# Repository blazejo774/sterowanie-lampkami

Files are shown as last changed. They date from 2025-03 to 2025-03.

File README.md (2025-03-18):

# 🔴🟢🔵 Sterowanie Lampkami Choinkowymi

Projekt ma sterować serią diod LED, poprzez zmienianie ustawień diód na jedno z wielu ustawień, z których użytkownik może wybrać przystosowane dla niego oświetlenie. Projekt zaweria różne rodzaje oświetlenia, miedzy innymi:

- [ ] Oscylacja światełek czerwonych, zielonych lub niebieskich.
- [ ] Włączenie bądź wyłączenie poszczególnych kolorów.
- [ ] Inne niestandardowe ustawienia oświetlenia.

Można rozszerzyć ilość używanych diod, poprzez dodanie więcej gałęzi po 3 diody:
 - Zamiast 1 gałęzi z 3 diodami, tworzysz np. 7 równoległych gałęzi po 3 diody w szeregu.
 - Każda gałąź dostaje swój rezystor, np. 7 rezystorów po 120Ω dla zielonych LED-ów.
 - MOSFET steruje wszystkimi 7 gałęziami naraz.
 
👉 Zalety: Nie zmienia się napięcie, MOSFET łatwo steruje większą ilością diod.

## 📝 Dokumentacja

ℹ Kod → [**Dokumentacja**](https://github.com/blazejo774/sterowanie-lampkami/blob/d19fd1ce32649a07414ba25e057f50cffe792c03/%5BCODE%5D/main.c)

ℹ Wykaz elementów → [**Dokumentacja**](https://github.com/blazejo774/sterowanie-lampkami/blob/d19fd1ce32649a07414ba25e057f50cffe792c03/%5BELECTRONICS%5D/readme.md)

## ⭐ Software

💾 Kod → [**main.c**](https://github.com/blazejo774/sterowanie-lampkami/blob/d19fd1ce32649a07414ba25e057f50cffe792c03/%5BCODE%5D/main.c)

## 💡 Hardware

💾 Schemat Elektryczny → [**Schemat Elektryczny**](https://github.com/blazejo774/sterowanie-lampkami/blob/d19fd1ce32649a07414ba25e057f50cffe792c03/%5BELECTRONICS%5D/scheme.pdf)

💾 Schemat Płytki PCB TOP → [**Płytka-TOP**](https://github.com/blazejo774/sterowanie-lampkami/blob/d19fd1ce32649a07414ba25e057f50cffe792c03/%5BBOARD%5D/Board_TOP.pdf)

💾 Schemat Płytki PCB BOTTOM → [**Płytka-BOTTOM**](https://github.com/blazejo774/sterowanie-lampkami/blob/d19fd1ce32649a07414ba25e057f50cffe792c03/%5BBOARD%5D/Board_BOTTOM.pdf)

💾 Schemat Płytki PCB(IMAGE) → [**Płytka**](https://github.com/blazejo774/sterowanie-lampkami/blob/d19fd1ce32649a07414ba25e057f50cffe792c03/%5BBOARD%5D/BOARD.png)

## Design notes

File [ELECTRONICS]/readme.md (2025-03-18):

# Wykaz elementów użytych w układzie

🔴Diody LED 5mm czerwone - **JUS-19995**.

🟢Diody LED 5mm zielone - **JUS-19994**. 

🔵Diody LED 5mm niebieske - **JUS-19991**.

◾️ Tranzystory MOSFET typu N - **BUZ10**

◾️ Rezystory 470 Ω (podłączone do bramek tranzystorów MOSFET) - **TE Connectivity / Neohm - 6-2176611-5**

◾️ Rezystory 90 Ω (dla diod koloru niebieskiego 🔵  **Vishay / BC Components - MBA0204VC9009FCT00**

◾️ Rezystory 300 Ω (dla diod koloru czerwonego 🔴) **YAGEO- CFR-25JB-52-300R**

◾️ Rezystory 120 Ω (dla diod koloru 🟢) **TE Connectivity / Neohm - EP1WSS120RJ**

◾️ Mikrokontroler AVR - **ATMEL - ATmega328P-AU**

# ⚡ Obliczenia poboru mocy (3 diody w każdej gałęzi)

Rezystory ograniczające prąd dla LED

    🔴Czerwone diody (2V x 3 = 6V)

        Rezystor: 300Ω

    🔵Niebieskie diody (3.4V x 3 = 10.2V)

        Rezystor: 90Ω

    🟢Zielone diody (3.2V x 3 = 9.6V)

        Rezystor: 120Ω

Moc tracona na rezystorach

    🔴Czerwone diody → 0.36 W

    🔵Niebieskie diody → 0.108 W

    🟢Zielone diody → 0.144 W

Całkowity pobór mocy układu

    🚀Moc pobierana przez LED-y: 0.72 W

    🚀Moc pobierana przez mikrokontroler: 0.1 W

    🚀Łączna moc pobierana przez cały układ: 0.82 W

✅ Użyty zasilacz to → 12V, 500mA oraz 5V, 100mA

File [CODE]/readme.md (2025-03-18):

# ⭐ Kod - Dokumentacja

## 📚 Biblioteki

```c
#include <avr/io.h>
#include <util/delay.h>
```

Pierwsze **2** linie naszego kodu źródłowego mają za zadanie dołączyć poszczególnych i niezbędnych bibliotek do naszego projektu.

## ⚙ Optymalizacje

```c
#define GREEN 4
#define BLUE 3
#define RED 2
#define IDLE 0
void turnOnALL(int8_t led){
  PORTB &= ~(1 << IDLE);
  PORTD |= (1 << led); 
}
void turnOffALL(int8_t led){
  PORTD &= ~(1 << led); 
}
void turnOff(){
  PORTB |= (1 << IDLE);
  PORTD &= ~(1 << RED);  
  PORTD &= ~(1 << GREEN); 
  PORTD &= ~(1 << BLUE); 
}
```

Poniższa część kodu definiuje poszczególne numery **wyjść** na płytce jako odpowiednie im kolory, aby kod był bardziej czytelny. 

```c
#define GREEN 4
#define BLUE 3
#define RED 2
#define IDLE 0
```

💬 *Kolor IDLE jest kolorem testowym, który służył do sprawdzenia sprawności układu i nie jest wykorzystywany w finałowym produkcie.* 

Poniższa część kodu składa się z trzech funkcji.

```c
void turnOnALL(int8_t led){
  PORTB &= ~(1 << IDLE);
  PORTD |= (1 << led); 
}
void turnOffALL(int8_t led){
  PORTD &= ~(1 << led); 
}
void turnOff(){
  PORTB |= (1 << IDLE);
  PORTD &= ~(1 << RED);  
  PORTD &= ~(1 << GREEN); 
  PORTD &= ~(1 << BLUE); 
}
```
Funkcja **turnOnALL** bierze jedną wartość *(np. GREEN)* i włącza wszystkie diody na wyjściu *(np. GREEN (PORTD4))*.

💬 *Testowy kolor IDLE służył do sprawdzenia, czy program działa w momencie gdy wszystkie inne diody były wyłączone. W momencie*
*włączenia jednej lub więcej diód owy kolor był wyłączony.* 

Funkcja **turnOffALL** bierze jedną wartość *(np. GREEN)* i wyłącza wszystkie diody na wyjściu *(np. GREEN (PORTD4))*.

Funkcja **turnOff** wyłącza wszystkie diody.

💬 *Program w tym momencie wciąż był włączony i do sprawdzenia, czy wciąż działał służyło włączenie diody IDLE.* 

## 🧠 Main

Reszta kodu została przedstawiona poniżej.

```c
int main(void)
{
  uint16_t btn_i = 5000;
  uint16_t led_i = 0;
  uint16_t delay = 3000;
  uint16_t delayshort = 1500;
  uint16_t delayshortest = 600;

  DDRD |= (1 << 2); // 2 Output
  DDRD |= (1 << 3); // 3 Output
  DDRD |= (1 << 4); // 4 Output

  DDRB |= (1 << 0); // 8 Output
  DDRB &= ~(1 << 5); // PB5 Input
  PORTB |= (1 << 5); // PB5 Pull-Up
  
  turnOff();

  while (1)
  {// Button
    if(!(PINB & (1 << PB5))) {
      btn_i--;
      if(!btn_i) {
        btn_i = 5000;
        led_i++;
      }
    }
    else {
      btn_i = 50;
    }
    switch (led_i)
    {
      case 1:
        turnOnALL(RED);
        turnOnALL(GREEN);
        turnOnALL(BLUE);
        break;
      case 2:
        turnOnALL(RED);
        turnOffALL(BLUE);
        turnOffALL(GREEN);
        break;
      case 3:
        turnOffALL(RED);
        turnOnALL(BLUE);
        turnOffALL(GREEN);
        break;
      case 4:
        turnOffALL(RED);
        turnOffALL(BLUE);
        turnOnALL(GREEN);
        break;
      case 5:
        delay--;
        switch (delay)
        {
        case 2000:
          turnOff();
          turnOnALL(RED);
          break;
        case 1000:
          turnOff();
          turnOnALL(BLUE);
          break;
        case 0:
          turnOff();
          turnOnALL(GREEN);
          delay = 3000;
          break;
        default:
          break;
        }
        break;
      case 6:
        delayshort--;
        switch (delayshort)
        {
          case 1000:
            turnOff();
            turnOnALL(RED);
            break;
          case 500:
            turnOff();
            turnOnALL(BLUE);
            break;
          case 0:
            turnOff();
            turnOnALL(GREEN);
            delayshort = 1500;
            break;
          default:
            break;
        }
        break;
      case 7:
        delayshortest--;
        switch (delayshortest)
        {
          case 400:
            turnOff();
            turnOnALL(RED);
            break;
          case 200:
            turnOff();
            turnOnALL(BLUE);
            break;
          case 0:
            turnOff();
            turnOnALL(GREEN);
            delayshortest = 600;
            break;
          default:
            break;
        }
        break;    
      case 8:
        turnOff();
        led_i = 0;
        break;
      default:
        break;
    }
    _delay_ms(1);
  }
}
```

Pierwsza część tego kodu służy do deklaracji ważnych dla tego programu zmiennych i funkcji.

```c
int main(void)
{
  uint16_t btn_i = 5000;
  uint16_t led_i = 0;
  uint16_t delay = 3000;
  uint16_t delayshort = 1500;
  uint16_t delayshortest = 600;

  DDRD |= (1 << 2); // 2 Output
  DDRD |= (1 << 3); // 3 Output
  DDRD |= (1 << 4); // 4 Output

  DDRB |= (1 << 0); // 8 Output
  DDRB &= ~(1 << 5); // PB5 Input
  PORTB |= (1 << 5); // PB5 Pull-Up
  
  turnOff();
.
.
.
```

Zmienne **btn_i** oraz **led_i** służą do obsługi przycisku.

Zmienne **delay**, **delayshort** oraz **delayshortest** służą do obsługi pewnych ustawień świateł. Te zmienne są zegarami.

Części z komentarzami typu **2 Output** deklarują wyjścia na diody, natomiast **PB5 Input** jest wyjściem obsługującym przycisk.

Funkcja **turnOff** jest zadeklarowana, aby upewnić się, że program zacznie z wyłączonymi diodami.

```c
.
.
.
  while (1)
  {// Button
    if(!(PINB & (1 << PB5))) {
      btn_i--;
      if(!btn_i) {
        btn_i = 5000;
        led_i++;
      }
    }
    else {
      btn_i = 50;
    }
.
.
.
```

Początek tej pentli obsługuje przycisk, funkcja ta zapobiega zbyt wielu kliknięciom. Kliknięcie przycisku powoduje zwiększenie

zmiennej **led_i** o `1`. Powoduje do zmiane ustawień na nowe instrukcje, których lista została podana poniżej:

```c
.
.
.
    switch (led_i)
    {
      case 1:
        turnOnALL(RED);
        turnOnALL(GREEN);
        turnOnALL(BLUE);
        break;
      case 2:
        turnOnALL(RED);
        turnOffALL(BLUE);
        turnOffALL(GREEN);
        break;
      case 3:
        turnOffALL(RED);
        turnOnALL(BLUE);
        turnOffALL(GREEN);
        break;
      case 4:
        turnOffALL(RED);
        turnOffALL(BLUE);
        turnOnALL(GREEN);
        break;
      case 5:
        delay--;
        switch (delay)
        {
        case 2000:
          turnOff();
          turnOnALL(RED);
          break;
        case 1000:
          turnOff();
          turnOnALL(BLUE);
          break;
        case 0:
          turnOff();
          turnOnALL(GREEN);
          delay = 3000;
          break;
        default:
          break;
        }
        break;
      case 6:
        delayshort--;
        switch (delayshort)
        {
          case 1000:
            turnOff();
            turnOnALL(RED);
            break;
          case 500:
            turnOff();
            turnOnALL(BLUE);
            break;
          case 0:
            turnOff();
            turnOnALL(GREEN);
            delayshort = 1500;
            break;
          default:
            break;
        }
        break;
      case 7:
        delayshortest--;
        switch (delayshortest)
        {
          case 400:
            turnOff();
            turnOnALL(RED);
            break;
          case 200:
            turnOff();
            turnOnALL(BLUE);
            break;
          case 0:
            turnOff();
            turnOnALL(GREEN);
            delayshortest = 600;
            break;
          default:
            break;
        }
        break;    
      case 8:
        turnOff();
        led_i = 0;
        break;
      default:
        break;
    }
    _delay_ms(1);
  }
}
```
1️⃣ **Ustawienie**:

Wszystkie diody się palą.

🟢🔵🔴   IDLE ⚫

2️⃣ **Ustawienie**:

Wszystkie diody czerwone się palą, reszta jest wyłączona.

⚫⚫🔴   IDLE ⚫

3️⃣ **Ustawienie**:

Wszystkie diody niebieskie się palą, reszta jest wyłączona.

⚫🔵⚫   IDLE ⚫

4️⃣ **Ustawienie**:

Wszystkie diody niebieskie się palą, reszta jest wyłączona.

🟢⚫⚫   IDLE ⚫

5️⃣ **Ustawienie**:

Aktywny kolor zmienia się na każdy kolor w kolejności **ZIELONY → NIEBIESKI → CZERWONY**.

Kolory zmieniają się co **sekunde**.

⚫⚫🔴   IDLE ⚫  →  ⚫🔵⚫   IDLE ⚫  →  🟢⚫⚫   IDLE ⚫

6️⃣ **Ustawienie**:

Aktywny kolor zmienia się na każdy kolor w kolejności **ZIELONY → NIEBIESKI → CZERWONY**.

Kolory zmieniają się co **pół sekundy**.

⚫⚫🔴   IDLE ⚫  →  ⚫🔵⚫   IDLE ⚫  →  🟢⚫⚫   IDLE ⚫

7️⃣ **Ustawienie**:

Aktywny kolor zmienia się na każdy kolor w kolejności **ZIELONY → NIEBIESKI → CZERWONY**.

Kolory zmieniają się co **0,2 sekundy**.

⚫⚫🔴   IDLE ⚫  →  ⚫🔵⚫   IDLE ⚫  →  🟢⚫⚫   IDLE ⚫

8️⃣ **Ustawienie**:

Wszystkie kolory się wyłączają. Numer danego ustawienia zamienia się na 0️⃣.

⚫⚫⚫   IDLE 🟡

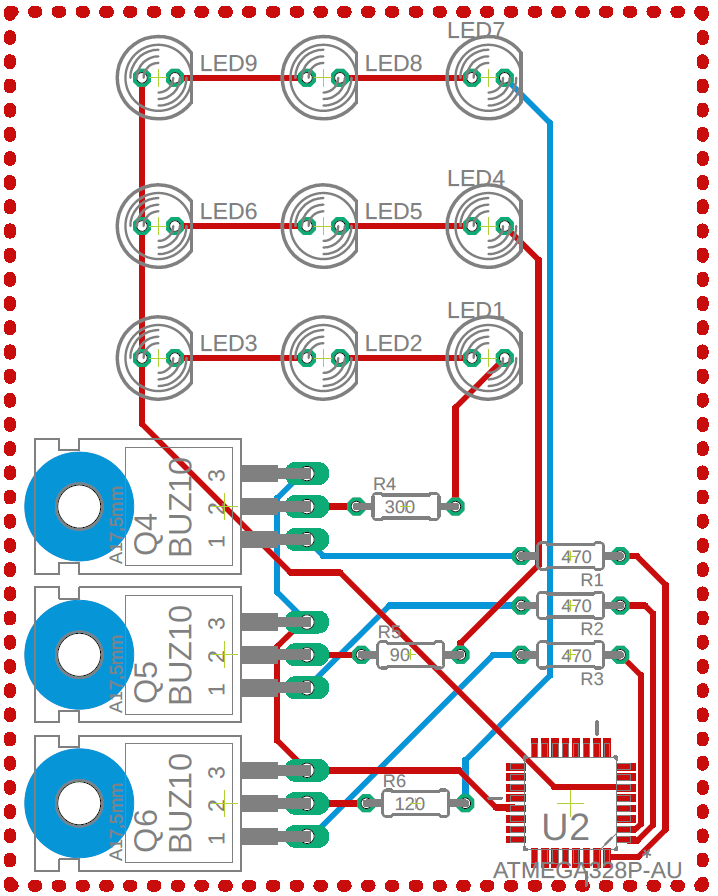
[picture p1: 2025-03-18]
[BOARD]/BOARD.png

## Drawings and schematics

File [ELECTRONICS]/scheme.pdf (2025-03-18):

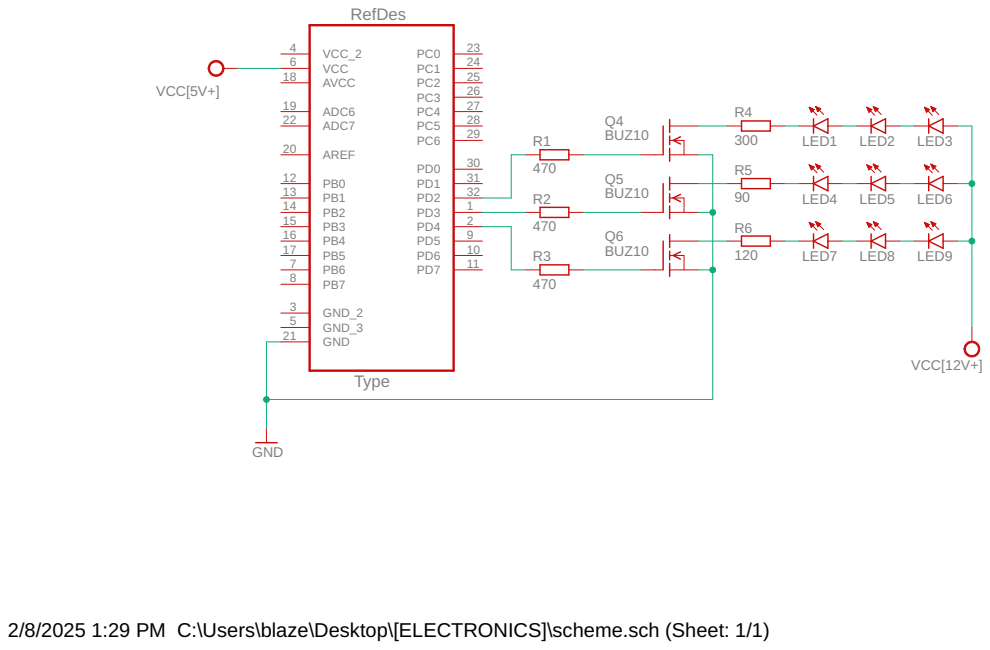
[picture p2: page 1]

2/8/2025 1:29 PM C:\Users\blaze\Desktop\[ELECTRONICS]\scheme.sch (Sheet: 1/1)

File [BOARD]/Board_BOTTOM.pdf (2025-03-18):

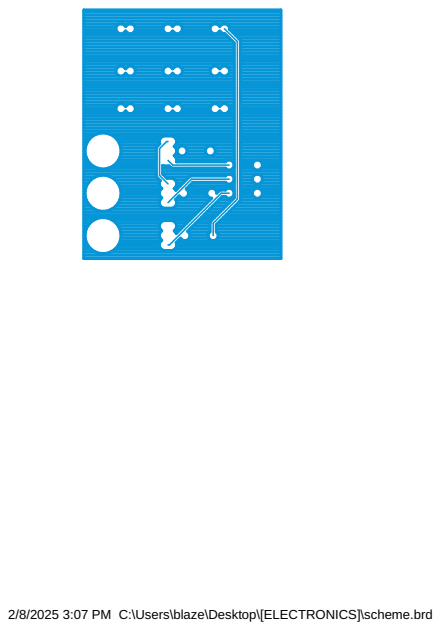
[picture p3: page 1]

2/8/2025 3:07 PM C:\Users\blaze\Desktop\[ELECTRONICS]\scheme.brd

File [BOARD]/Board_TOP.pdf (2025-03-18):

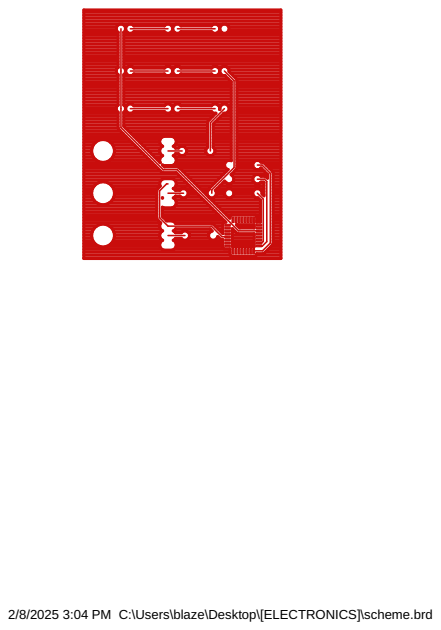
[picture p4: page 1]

2/8/2025 3:04 PM C:\Users\blaze\Desktop\[ELECTRONICS]\scheme.brd

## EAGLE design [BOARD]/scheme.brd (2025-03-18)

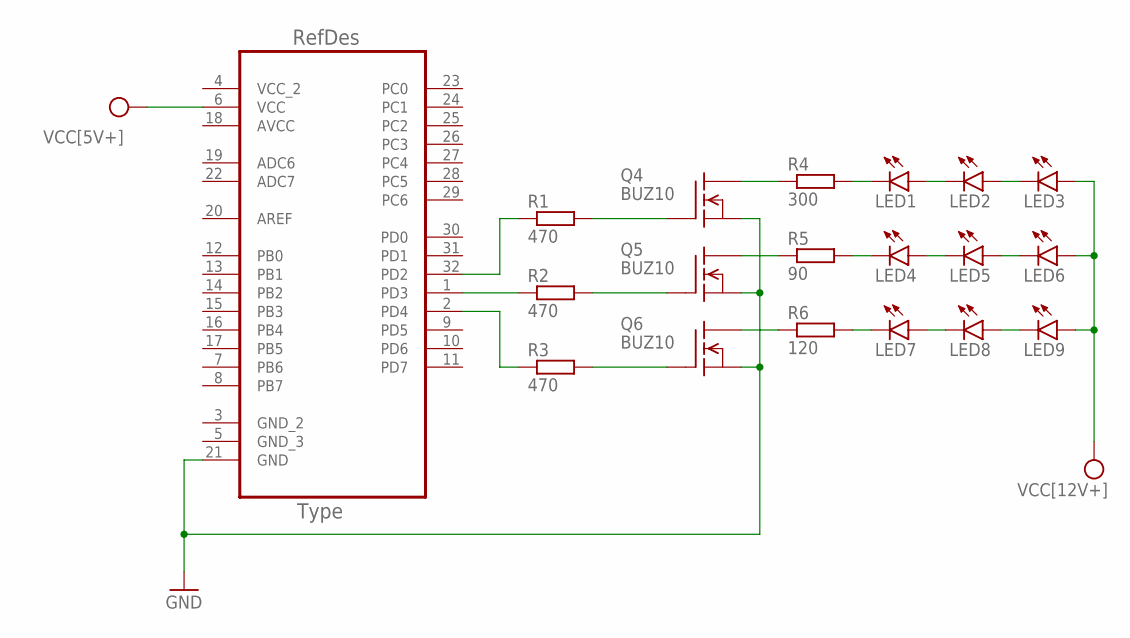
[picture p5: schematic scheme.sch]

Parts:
LED1, LED2, LED3, LED4, LED5, LED6, LED7, LED8, LED9: LED5MM
Q4, Q5, Q6: BUZ10; TO220
R1, R2, R3: 470; 0204/7
R4: 300; 0204/7
R5: 90; 0204/7
R6: 120; 0204/7
U2: ATMEGA328P-AU; QFP80P900X900X120-32N

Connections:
AVCC: U2.18 (AVCC)
GND: Q4.3 (S), Q5.3 (S), Q6.3 (S), U2.21 (GND)
unnamed: LED4.K (C), R5.2
unnamed: LED4.A, LED5.K (C)
unnamed: LED1.K (C), R4.2
unnamed: LED1.A, LED2.K (C)
unnamed: LED2.A, LED3.K (C)
unnamed: LED5.A, LED6.K (C)
unnamed: LED7.K (C), R6.2
unnamed: LED7.A, LED8.K (C)
unnamed: LED8.A, LED9.K (C)
unnamed: Q6.2 (D), R6.1
unnamed: Q5.2 (D), R5.1
unnamed: Q4.2 (D), R4.1
unnamed: Q4.1 (G), R1.2
unnamed: Q5.1 (G), R2.2
unnamed: Q6.1 (G), R3.2
unnamed: R2.1, U2.1 (PD3)
unnamed: R3.1, U2.2 (PD4)
unnamed: R1.1, U2.32 (PD2)
VCC: LED3.A, LED6.A, LED9.A, U2.6 (VCC)
VCC_2: U2.4 (VCC_2)

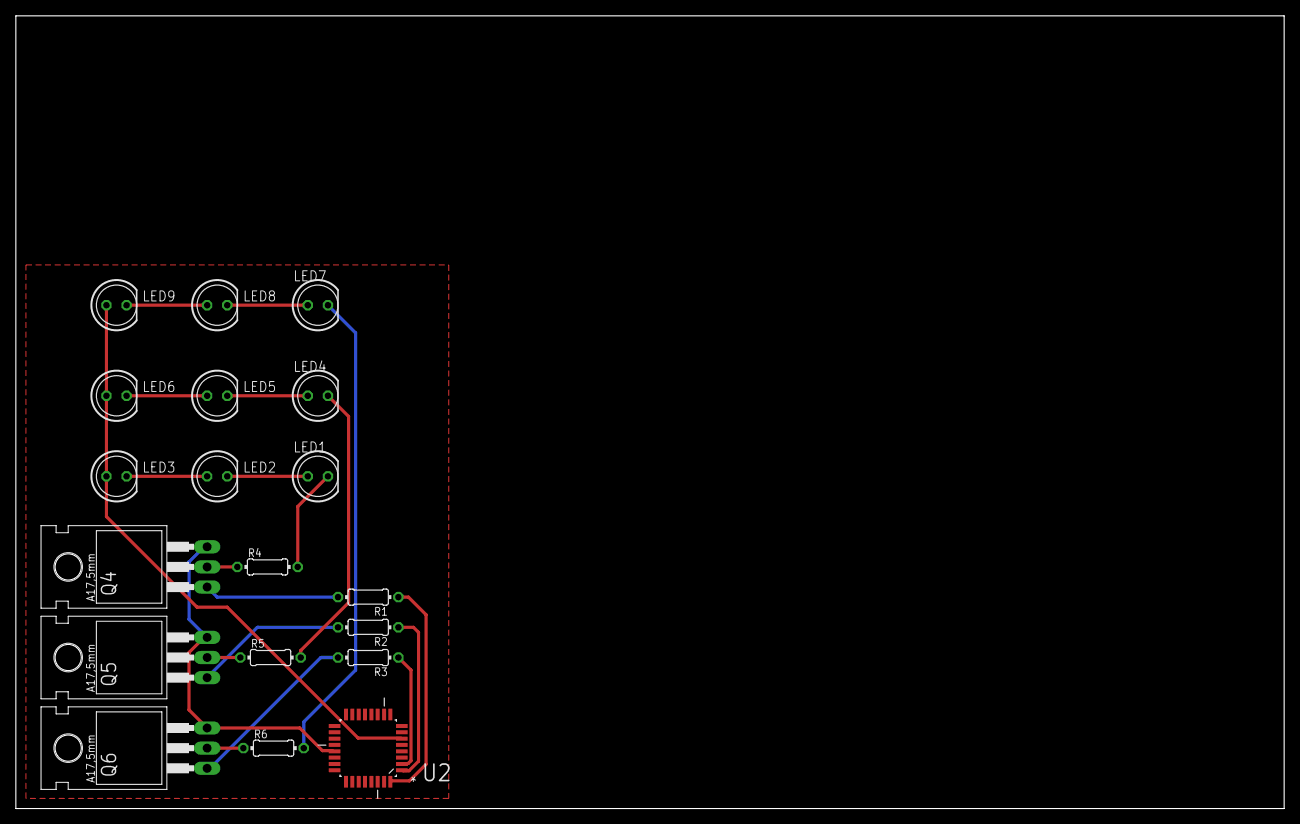
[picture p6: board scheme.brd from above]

Board: 2 copper layers, 160.0 x 100.0 mm, 19 parts (0 on the bottom side), 20 nets.
